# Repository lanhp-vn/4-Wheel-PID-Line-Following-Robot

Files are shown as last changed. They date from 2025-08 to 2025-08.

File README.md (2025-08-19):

# 4-Wheel Line Following Robot

An Arduino-based autonomous line following robot designed for competitive racing and educational purposes. This project demonstrates advanced robotics concepts including PID control, sensor fusion, obstacle avoidance, and differential drive navigation.

**Video Demo:** [Watch the robot in action](https://www.youtube.com/watch?v=uRDj3uBrsaU)

## Project Overview

This project represents my complete understanding and implementation of advanced robotics concepts. Every library, algorithm, and control logic was personally developed, written, and tested by me through extensive experimentation and iterative development.

## Key Features

- **4-Wheel Differential Drive**: Precise control with independent motor control
- **Advanced Line Following**: BFD-1000 5-channel IR sensor array with custom PID control algorithm
- **Obstacle Avoidance**: Personal ultrasonic sensor integration and avoidance logic
- **Encoder Feedback**: Custom H206 encoder reading and calculation algorithms
- **Kalman Filtering**: Personal sensor noise reduction implementation
- **Modular Design**: Easy component mounting and maintenance
- **Competition Ready**: Optimized for line following competitions through personal testing and tuning

## Hardware Components

| Component | Model | Purpose |
|---|---|---|
| **Microcontroller** | Arduino UNO | Main control unit |
| **Line Sensor** | BFD-1000 | 5-channel IR tracking module |
| **Motors** | 4x DC Motors | Differential drive system |
| **Motor Driver** | L298N H-bridge | Motor control and direction |
| **Distance Sensors** | HC-SR04 Ultrasonic | Obstacle detection |
| **Encoders** | H206 | Position and speed feedback |
| **Chassis** | Acrylic | Lightweight and modular design |
| **Power** | External Battery Pack | Barrel jack connection |

## Project Structure

```
main/
├── main.ino                    # Main robot program (100% custom written by me)
├── libraries/                   # Custom Arduino libraries
│   ├── BFD1000/               # Line sensor library
│   ├── PID Calculation/       # PID control algorithms
│   ├── Test encoder lib/      # Encoder testing
│   ├── Test LF sensor/        # Line sensor testing
│   ├── Test motor/            # Motor driver testing
│   ├── Test obstacle avoidance/ # Obstacle avoidance testing
│   └── Ultrasonic - Measuring distance/ # Distance measurement
├── 3d_models/                 # 3D printable parts
│   ├── adjusting pad v1.stl   # Sensor adjustment mount
│   └── BFD1000 pad v1.stl     # Line sensor mount
└── docs/                      # Documentation and schematics
```

## Personal Development Work

**All libraries and algorithms in this project were personally developed, written, and tested by me.** This includes:

### Libraries
- **Motor_Driver.h/cpp**: L298N motor driver control library
- **LFsensor.h/cpp**: BFD-1000 line sensor interface library
- **Encoder_Read.h/cpp**: H206 encoder reading and calculations library
- **Ultrasonic.h/cpp**:  HC-SR04 ultrasonic sensor control library
- **SimpleKalmanFilter.h/cpp**: sensor noise filtering implementation

### Control Algorithms (Personally Developed)
- **PID Control**: Custom PID algorithm written, tested, and fine-tuned through experimentation
- **Obstacle Avoidance**: Personal obstacle detection and avoidance logic
- **Encoder-Based Navigation**: Custom distance and angle calculation algorithms
- **State Management**: Complete state machine for robot operating modes

### Development Process
Every algorithm, library function, and control logic was:
1. Designed from scratch based on component datasheets
2. Written entirely by me in C++ for Arduino
3. Tested through extensive experimentation with real hardware
4. Fine-tuned through iterative development and performance optimization
5. Integrated into a complete system through systematic testing

## Main Program Development

### main.ino - My Complete Robot Control System
This main Arduino program represents my complete understanding and implementation of:

- **Complete State Machine**: All robot operating modes (line following, obstacle avoidance, turning, etc.)
- **PID Control Integration**: My custom PID algorithm integrated with motor control
- **Sensor Management**: Coordination of all sensors (line sensors, ultrasonic, encoders)
- **Motor Control Logic**: Integration with my custom motor driver library
- **Interrupt Handling**: Custom encoder interrupt routines for precise position tracking
- **Error Handling**: Robust error detection and recovery mechanisms
## Technical Specifications

### PID Parameters
```cpp
const float Kp = 40;    // Proportional gain
const float Ki = 0;      // Integral gain  
const float Kd = 45;     // Derivative gain
const int init_speed = 200;  // Base speed
const int max_speed = 240;   // Maximum speed
```

### Pin Connections
```cpp
// Motor Driver (L298N)
#define ENA A0, ENB A1
#define IN1 4, IN2 5, IN3 6, IN4 7

// Line Sensors (BFD-1000)
#define S1 9, S2 10, S3 11, S4 12, S5 13

// Ultrasonic Sensors
#define Trig 8, Front A2, Right A4, Left A5

// Encoders
#define leftEncoder 2, rightEncoder 3
```

## Getting Started

### Prerequisites
- Arduino IDE 1.8.x or later
- Arduino UNO board
- Required hardware components (see Hardware Components table)

### Installation
1. Clone this repository
2. Open `main/main.ino` in Arduino IDE
3. Connect hardware according to pin definitions
4. Upload to Arduino UNO

## Personal Achievement

This project represents my complete understanding and implementation of advanced robotics concepts:

- **From Theory to Practice**: Implemented PID control, sensor fusion, and navigation algorithms
- **Hardware Integration**: Successfully integrated multiple sensors and actuators
- **Software Architecture**: Designed modular, maintainable code structure
- **Testing & Optimization**: Fine-tuned performance through extensive experimentation
- **Problem Solving**: Developed solutions for real-world robotics challenges

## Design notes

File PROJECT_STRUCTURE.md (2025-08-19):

# Project Structure Overview

## 📁 Complete File Organization

```
4-Wheel-Line-Following-Robot/
├── README.md                    # Main project documentation
├── QUICKSTART.md               # Quick start guide
├── project_config.md           # Technical configuration details
├── PROJECT_STRUCTURE.md        # This file - project overview
├── Class Diagram.docx          # Original class diagram
├── Midterm Assessment.pdf      # Course assessment document
├── robot.heic                  # Robot image
│
├── main/                       # Main source code
│   ├── main.ino                    # Main Arduino program
│   ├── Encoder_Read.cpp            # Encoder library implementation
│   ├── Encoder_Read.h              # Encoder library header
│   ├── LFsensor.cpp                # Line sensor library implementation
│   ├── LFsensor.h                  # Line sensor library header
│   ├── Motor_Driver.cpp            # Motor driver library implementation
│   ├── Motor_Driver.h              # Motor driver library header
│   ├── SimpleKalmanFilter.cpp      # Kalman filter implementation
│   ├── SimpleKalmanFilter.h        # Kalman filter header
│   ├── Ultrasonic.cpp              # Ultrasonic sensor library
│   └── Ultrasonic.h                # Ultrasonic sensor header
│
├── src/libraries/              # Testing and development libraries
│   ├── BFD1000/               # Line sensor testing
│   │   └── BFD1000.ino
│   ├── PID Calculation/       # PID control algorithms
│   │   ├── PID Calculation.ino
│   │   ├── PIDcal.cpp
│   │   └── PIDcal.h
│   ├── Test encoder lib/      # Encoder testing
│   │   ├── Encoder_Read.cpp
│   │   ├── Encoder_Read.h
│   │   └── Test encoder lib.ino
│   ├── Test LF sensor/        # Line sensor testing
│   │   └── sketch_nov13c/
│   │       ├── LFsensor.cpp
│   │       ├── LFsensor.h
│   │       └── sketch_nov13c.ino
│   ├── test motor/            # Motor driver testing
│   │   └── test motor.ino
│   ├── Test obstacle avoidance/ # Obstacle avoidance testing
│   │   ├── Encoder_Read.cpp
│   │   ├── Encoder_Read.h
│   │   ├── Motor_Driver.cpp
│   │   ├── Motor_Driver.h
│   │   ├── SimpleKalmanFilter.cpp
│   │   ├── SimpleKalmanFilter.h
│   │   ├── Test obstacle avoidance.ino
│   │   ├── Ultrasonic.cpp
│   │   └── Ultrasonic.h
│   ├── Test ultrasonic lib/   # Ultrasonic testing
│   │   ├── Test ultrasonic lib.ino
│   │   ├── Ultrasonic.cpp
│   │   └── Ultrasonic.h
│   ├── Turning angles/        # Turning angle testing
│   │   └── Turning angles.ino
│   └── Ultrasonic - Measuring distance/ # Distance measurement
│       └── Measuring distance/
│           ├── Measuring distance.ino
│           ├── UTSN_MeasDist.cpp
│           └── UTSN_MeasDist.h
│
├── src/3d_models/             # 3D printable parts
│   ├── adjusting pad v1.stl   # Sensor adjustment mount
│   ├── adjusting pad v1_0.15mm_PLA_MK3S_24m.gcode
│   ├── BFD1000 pad v1.stl     # Line sensor mount
│   └── BFD1000 pad v1_0.15mm_PLA_MK3S_1h4m.gcode
│
└── docs/                      # Additional documentation
    └── (future documentation files)
```

## 🔄 File Renaming Summary

### Original → New Names
- `Main_program.ino` → `main.ino`
- `Main_program/` → `main/` (main source code)
- `Arduino Libs - Robot Studio/` → `main/libraries/`
- `3Dparts_LineFollowingSensor/` → `main/3d_models/`

### Key Benefits of New Structure
1. **Clear Separation**: Source code, libraries, and 3D models are clearly organized
2. **Standard Naming**: Follows common Arduino project conventions
3. **Easy Navigation**: Logical grouping of related files
4. **Professional Appearance**: Suitable for GitHub and portfolio use

## 📚 Library Organization

### Core Libraries (in src/)
These are the main libraries used by the robot:
- **Motor_Driver**: Controls L298N motor driver
- **LFsensor**: Interfaces with BFD-1000 line sensor
- **Encoder_Read**: Handles H206 encoder readings
- **Ultrasonic**: Manages HC-SR04 sensors
- **SimpleKalmanFilter**: Reduces sensor noise

### Testing Libraries (in src/libraries/)
These are for development and testing:
- **BFD1000**: Line sensor testing and calibration
- **PID Calculation**: PID algorithm development
- **Test encoder lib**: Encoder functionality testing
- **Test LF sensor**: Line sensor testing
- **test motor**: Motor driver testing
- **Test obstacle avoidance**: Obstacle avoidance testing
- **Test ultrasonic lib**: Ultrasonic sensor testing
- **Turning angles**: Turning precision testing

## 🎯 Usage Guidelines

### For End Users
1. Use files in `main/` for the main robot
2. Refer to `README.md` for setup instructions
3. Use `QUICKSTART.md` for quick setup
4. Check `project_config.md` for technical details

### For Developers
1. Use `main/libraries/` for component testing
2. Modify main code in `main/main.ino`
3. Test individual components before integration
4. Use provided test libraries for debugging

### For Educators
1. Use as a complete robotics project example
2. Demonstrate PID control implementation
3. Show sensor fusion techniques
4. Illustrate modular software design

## 🚀 GitHub Repository Structure

This structure is optimized for GitHub with:
- Clear documentation at the top level
- Organized source code in `main/`
- Comprehensive testing libraries
- 3D models for hardware reproduction
- Professional README and guides

## 📝 Maintenance Notes

- Keep original files as backup until new structure is verified
- Update documentation when modifying code
- Test all components after any changes
- Maintain consistent naming conventions
- Version control all changes

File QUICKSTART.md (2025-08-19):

# Quick Start Guide

Get your 4-Wheel Line Following Robot up and running in minutes!

## 🚀 Quick Setup

### 1. Hardware Assembly
- Mount Arduino UNO on the acrylic chassis
- Connect BFD-1000 line sensor to pins 9-13
- Connect L298N motor driver to pins 4-7, A0-A1
- Connect ultrasonic sensors to pins 8, A2, A4, A5
- Connect encoders to pins 2-3
- Connect external battery pack via barrel jack

### 2. Software Setup
1. **Download Code**: Clone this repository
2. **Open Arduino IDE**: Open `main/main.ino`
3. **Select Board**: Tools → Board → Arduino Uno
4. **Select Port**: Tools → Port → (your Arduino port)
5. **Upload**: Click Upload button or Ctrl+U

### 3. First Test
1. **Power On**: Connect battery pack
2. **Place on Line**: Put robot on a black line on white surface
3. **Watch it Go**: Robot should automatically follow the line!

## ⚡ Quick Configuration

### Basic PID Tuning
```cpp
// In line_following_robot.ino, adjust these values:
const float Kp = 40;    // Start with 40, increase for faster response
const float Ki = 0;      // Keep at 0 initially
const float Kd = 45;     // Start with 45, increase for stability
```

### Speed Adjustment
```cpp
const int init_speed = 200;  // Base speed (0-255)
const int max_speed = 240;   // Maximum speed
```

### Obstacle Detection
```cpp
const float detect_obstacle = 20;  // Detection distance in cm
```

## 🔧 Common Issues & Solutions

### Robot Not Moving
- Check motor connections
- Verify battery voltage
- Check motor driver connections

### Poor Line Following
- Clean line sensor lenses
- Adjust PID values
- Check line contrast (black on white)

### Encoder Errors
- Verify encoder connections
- Check interrupt pins (2, 3)
- Ensure proper mounting

### Ultrasonic Issues
- Check sensor connections
- Verify trigger/echo pins
- Clean sensor surfaces

## 📊 Performance Optimization

### For Speed
- Increase `Kp` value
- Increase `init_speed`
- Reduce `Kd` value

### For Stability
- Increase `Kd` value
- Reduce `init_speed`
- Fine-tune `Kp`

### For Obstacle Avoidance
- Adjust `detect_obstacle` distance
- Modify avoidance algorithm in code
- Test different sensor positions

## 🎯 Competition Tips

1. **Calibrate Sensors**: Test on actual competition surface
2. **Optimize PID**: Fine-tune for track characteristics
3. **Battery Check**: Ensure full charge before competition
4. **Speed vs Accuracy**: Find optimal balance for your track
5. **Practice Runs**: Test on similar track layouts

## 📱 Serial Monitor

Connect to Arduino via Serial Monitor (9600 baud) to see:
- Current operating mode
- Sensor readings
- PID calculations
- Error values

## 🆘 Need Help?

- Check the main [README.md](README.md) for detailed information
- Review [project_config.md](project_config.md) for technical details
- Test individual components using the test libraries in `src/libraries/`
- Ensure all connections match the pin definitions

---

**Happy Robot Building! 🤖**

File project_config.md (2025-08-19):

# Project Configuration

## Pin Definitions

### Motor Driver (L298N)
```cpp
#define ENA A0    // Left motor speed control
#define ENB A1    // Right motor speed control
#define IN1 4     // Left motor direction 1
#define IN2 5     // Left motor direction 2
#define IN3 6     // Right motor direction 1
#define IN4 7     // Right motor direction 2
```

### Line Sensors (BFD-1000)
```cpp
#define S1 9      // Leftmost sensor
#define S2 10     // Left sensor
#define S3 11     // Center sensor
#define S4 12     // Right sensor
#define S5 13     // Rightmost sensor
```

### Ultrasonic Sensors
```cpp
#define Trig 8    // Trigger pin (shared)
#define Front A2  // Front sensor echo
#define Right A4  // Right sensor echo
#define Left A5   // Left sensor echo
```

### Encoders
```cpp
#define leftEncoder 2   // Left wheel encoder
#define rightEncoder 3  // Right wheel encoder
```

## Control Parameters

### PID Control
```cpp
const float Kp = 40;           // Proportional gain
const float Ki = 0;            // Integral gain
const float Kd = 45;           // Derivative gain
const int init_speed = 200;    // Base speed
const int min_speed = 0;       // Minimum speed
const int max_speed = 240;     // Maximum speed
const int turn_speed = 170;    // Turning speed
```

### Obstacle Detection
```cpp
const float detect_obstacle = 20;  // Detection distance in cm
const float front_obstacle = 20;   // Front obstacle threshold
```

### Encoder Configuration
```cpp
const int delay_90deg = 450;   // Delay for 90-degree turn
```

### Kalman Filter
```cpp
const float mea_e = 2;         // Measurement uncertainty
const float est_e = 2;         // Estimation uncertainty
const float q = 0.07;          // Process variance
```

## Operating Modes

```cpp
const int FINISH = 0;              // Finish line detected
const int FOLLOWING_LINE = 1;      // Normal line following
const int STOP = 2;                // No line detected
const int TURNING_left = 3;        // Turning left
const int TURNING_right = 4;       // Turning right
const int AVOIDING_OBSTACLE = 5;   // Obstacle avoidance
```

## Hardware Specifications

### Motors
- **Type**: DC Motors with H-bridge control
- **Control**: PWM speed control (0-255)
- **Direction**: Bidirectional control

### Sensors
- **Line Sensor**: BFD-1000 5-channel IR array
- **Distance**: HC-SR04 ultrasonic (2-400cm range)
- **Encoders**: H206 quadrature encoders

### Power
- **Voltage**: External battery pack
- **Connection**: Barrel jack
- **Regulation**: Arduino UNO voltage regulation

## Calibration Values

### Line Sensor Thresholds
- **Black Line**: Digital LOW (0)
- **White Surface**: Digital HIGH (1)

### Encoder Calculations
- **Wheel Diameter**: Configured in Encoder_Read library
- **Pulses per Revolution**: 40 pulses per revolution
- **Distance Calculation**: Based on wheel circumference

### Ultrasonic Calibration
- **Speed of Sound**: 340 m/s (standard)
- **Temperature Compensation**: Not implemented
- **Filtering**: Kalman filter for noise reduction

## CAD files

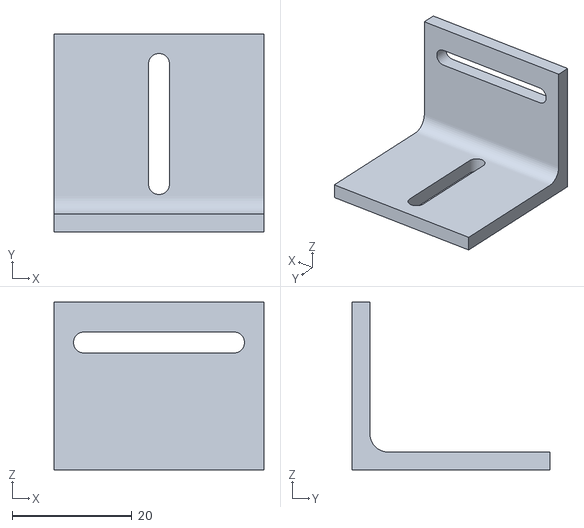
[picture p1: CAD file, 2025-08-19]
main/3d_models/BFD1000 pad v1.stl
35.0 x 33.0 x 28.0

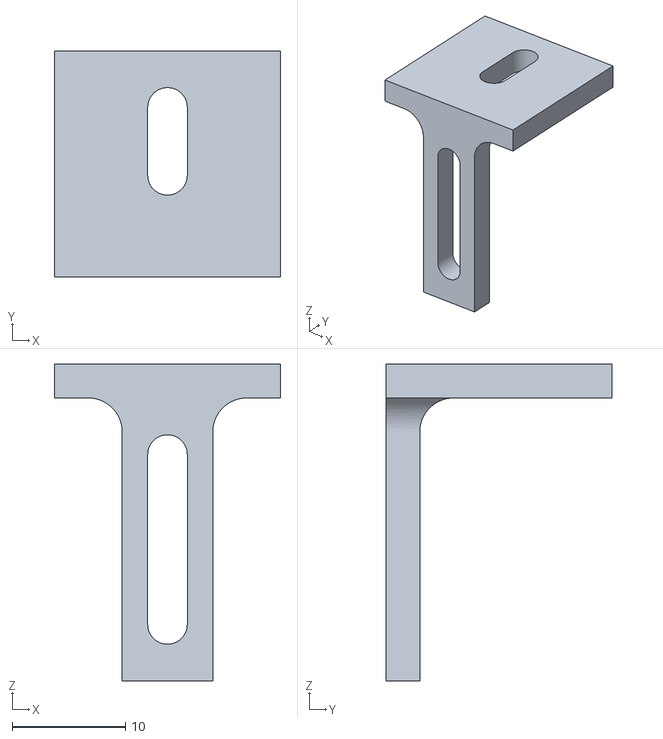
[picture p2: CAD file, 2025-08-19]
main/3d_models/adjusting pad v1.stl
20.0 x 20.0 x 28.0

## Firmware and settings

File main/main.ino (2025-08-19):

//**********Include libraries**********//
#include "Motor_Driver.h"
#include "Encoder_Read.h"
#include "Ultrasonic.h"
#include "LFsensor.h"
#include "SimpleKalmanFilter.h"


//**********4 Channels Ultrasonic Sensors**********//
#define Trig 8
#define Front A2
#define Right A4
#define Left A5

//**********6 Channels L298N Motor Driver**********//
#define ENA A0
#define ENB A1
#define IN1 4
#define IN2 5
#define IN3 6
#define IN4 7
//**********5 Channels BFD1000 LF Sensor**********//
#define S1 9
#define S2 10
#define S3 11
#define S4 12
#define S5 13
//**********2 Channels H206 Encoders**********//
#define leftEncoder 2
#define rightEncoder 3


//------Declare SWITCH-CASE MODES------//
const int FINISH = 0;
const int FOLLOWING_LINE = 1;
const int STOP = 2;
const int TURNING_left = 3;
const int TURNING_right = 4;
const int AVOIDING_OBSTACLE = 5;
int obstacle;
float front_obstacle = 20; //in centimeters

//------Declare variables for Encoder_Read------//
volatile int left_count, right_count, rotation, rpm;
unsigned long timetaken, pevtime, dtime, finishtime; //to store millis()
float v, angle, dist, left_count_temp, right_count_temp;

//------Declare variables for rotating direction------//
const int right = 0;
const int left = 1;

//------Declare variables for calculatePID------//
float P, I, D, PIDval;
const float Kp = 40;
const float Ki = 0;
const float Kd = 45;
const int init_speed = 200;
const int min_speed = 0;
const int max_speed = 240;
const int turn_speed = 170;
const int delay_90deg = 450;

//------Declare variables for Ultrasonic------//
float meas_front, meas_left, meas_right;
const float detect_obstacle = 20; //in cm

//------Declare variables for LFsensor------//
int mode;
float error, prev_error;

//------Declare variables for LFsensor------//
const float mea_e = 2; //Measurement uncertainty
const float est_e = 2; //Estimation uncertainty
const float q = 0.07; //Process variance


//------DECLARE CLASSES FOR INCLUDED LIBRARIES------//
SimpleKalmanFilter kf = SimpleKalmanFilter(mea_e, est_e, q);
Motor_Driver driver = Motor_Driver(ENA, ENB, IN1, IN2, IN3, IN4);
Encoder_Read encoder = Encoder_Read();
Ultrasonic UTSN = Ultrasonic(Trig);
LFsensor LFS = LFsensor(S1, S2, S3, S4, S5);



//---------------------------VOID SETUP---------------------------//
void setup() {
  // put your setup code here, to run once:
  Serial.begin(9600);

  //------PINMODE------//
  pinMode(IN1, OUTPUT);
  pinMode(IN2, OUTPUT);
  pinMode(IN3, OUTPUT);
  pinMode(IN4, OUTPUT);

  pinMode(ENA, OUTPUT);
  pinMode(ENB, OUTPUT);

  pinMode(S1, INPUT);
  pinMode(S2, INPUT);
  pinMode(S3, INPUT);
  pinMode(S4, INPUT);
  pinMode(S5, INPUT);

  pinMode(Trig, OUTPUT);
  pinMode(Front, INPUT);
  pinMode(Right, INPUT);
  pinMode(Left, INPUT);

  pinMode(leftEncoder, INPUT);
  pinMode(rightEncoder, INPUT);
  digitalWrite(leftEncoder, HIGH);
  digitalWrite(rightEncoder, HIGH);

  //------VARIABLES------//
  P = I = D = PIDval = 0;
  left_count = right_count = pevtime = dtime = 0;
  left_count_temp = right_count_temp = 0;

  obstacle = 0;

  //------ATTACH INTERRUPTIONS------//
  attachInterrupt(digitalPinToInterrupt(leftEncoder), left_ISR, CHANGE);
  attachInterrupt(digitalPinToInterrupt(rightEncoder), right_ISR, CHANGE);
}



//---------------------------INTERRUPTION FUNCTIONS---------------------------//
void left_ISR()
{
  left_count++;
}

void right_ISR()
{
  right_count++;
  rotation++;
  dtime = millis();
  if(rotation>=40)
  {
    timetaken = millis() - pevtime  ;
    rpm = (1000/timetaken)*60; //rps = 1000/timetaken
    rpm = kf.updateEstimate(rpm);
    pevtime = millis();
    rotation = 0;
  }
}


//---------------------------FUNCTIONS---------------------------//
void setPIDspeed()
{
  P = error;
  I = I + error;
  D = error - prev_error;

  PIDval = (Kp * P) + (Ki * I) + (Kd * D);
  prev_error = error;

  int left_speed = init_speed - PIDval; 
  int right_speed = init_speed + PIDval;

  // The motor speed should not exceed the max PWM value
  left_speed = constrain(left_speed, min_speed, max_speed);
  right_speed = constrain(right_speed, min_speed, max_speed);

  driver.setSpeed(left_speed, right_speed);
}

//*****Allow robot to rotate at specified angle*****//
void turn(float aim_deg, int direction)
{

  float cur_angle = 0;
  float going_angle = 0;

  Serial.println(left_count);
  Serial.println(right_count);

  if (left_count_temp == 0 && right_count_temp == 0)
  {
    left_count_temp = left_count;
    right_count_temp = right_count;
  }
  
  cur_angle = encoder.angle_cal(left_count_temp, right_count_temp);
  Serial.print("cur angle: ");
  Serial.println(cur_angle);

  //Rotate right --> direction = 0
  //Rotate left --> direction = 1
  if (direction == 0)
  {driver.shiftRight();}
  if (direction == 1)
  {driver.shiftLeft();}

  going_angle = encoder.angle_cal(left_count, right_count) - cur_angle;
  Serial.print("going angle: ");
  Serial.println(going_angle);

  if (going_angle >= aim_deg)
  {
    driver.stopCar();
    delay(1000);
    left_count_temp = 0;
    right_count_temp = 0;
  }
}

//*****Allow robot to move at specified distance*****//
void move(float aim_dist) //aim_dist in meters
{
  float cur_dist = 0;
  float going_dist = 0;  

  if (right_count_temp == 0)
  {right_count_temp = right_count;}

  cur_dist = encoder.dist_cal(right_count_temp);
  Serial.print("current dist: "); 
  Serial.println(cur_dist);

  driver.forward();

  going_dist = encoder.dist_cal(right_count) - cur_dist;
  Serial.print("going distance: "); 
  Serial.println(going_dist);

  if (going_dist >= aim_dist)
  {
    driver.stopCar();
    delay(1000);
    right_count_temp = 0;
  }
}


//*****Reach finish line by brute-force testing*****//
void BForce_finish(int direction)
{
  int speed = 150;

  driver.setSpeed(speed, speed);

  driver.stopCar();
  delay(1000);

  //Right road --> direction = 0
  //Left road --> direction = 1
  switch(direction)
  {
    case right:
      driver.forward();
      delay(1800);
      driver.stopCar();
      delay(500);
      driver.turn_90deg(right, delay_90deg);
      driver.forward();
      delay(2770);
      driver.stopCar();
      delay(10000);
      break;

    case left:
      driver.forward();
      delay(1500);
      driver.stopCar();
      delay(500);
      driver.turn_90deg(left, delay_90deg);
      driver.forward();
      delay(2770);
      driver.stopCar();
      delay(10000);
      break;
  }
}

//*****Procedure for robot to avoid the obstacle ahead*****//
void obstacle_avoid(int meas_pin)
{
  int speed = 150;
  int X = 500;
  int Z = 1000;
  int Y = 0;
  bool obstacle_ahead = 30;
  bool no_obstacle;

  driver.setSpeed(speed, speed);

  driver.stopCar();
  delay(1000);

  driver.turn_90deg(right, delay_90deg);

  driver.forward();
  delay(X);
  Y += X;
  driver.stopCar();
  delay(1000);

  driver.turn_90deg(left, delay_90deg);

  no_obstacle = UTSN.no_obstacle(meas_front, obstacle_ahead);
  if (no_obstacle == false)
  {
    driver.turn_90deg(right, delay_90deg);
    driver.forward();
    delay(X);
    Y += X;
    driver.stopCar();
    delay(1000);
  }

  driver.forward();
  delay(Z);
  driver.stopCar();
  delay(1000);

  driver.turn_90deg(left, delay_90deg);

  no_obstacle = UTSN.no_obstacle(meas_front, obstacle_ahead);
  if (no_obstacle == false)
  { 
    driver.turn_90deg(right, delay_90deg);
    driver.forward();
    delay(Z/2);
    driver.stopCar();
    delay(1000);
  }

  driver.forward();
  delay(Y+500);
  driver.stopCar();
  delay(1000);

  driver.turn_90deg(right, delay_90deg);
  driver.stopCar();
  delay(1000);
}

//---------------------------FUNCTIONS for TESTING---------------------------//
//*****To test the correctness of rpm's calculation*****//
void test_rpm()
{
  driver.stopCar();
  delay(5000);

  driver.forward();
  delay(60000);

  int RPM = rpm;
  int rpm_compare = right_count/40;

  Serial.print("rpm: ");
  Serial.println(RPM);
  Serial.print("rpm_compare: ");
  Serial.println(rpm_compare);
  Serial.print("right count: ");
  Serial.println(right_count);
}

//*****To test the correctness of distance measured by ultrasonic sensors*****//
void test_UTSN()
{
  meas_front = kf.updateEstimate(UTSN.measDist(Front));
  Serial.print("front:"); Serial.print(meas_front); Serial.println();
  delay(50);
  
  meas_right = kf.updateEstimate(UTSN.measDist(Right));
  Serial.print("right:"); Serial.print(meas_right); Serial.println();
  delay(50);
  
  meas_left = kf.updateEstimate(UTSN.measDist(Left));
  Serial.print("left:"); Serial.print(meas_left); Serial.println();

  Serial.println();

  delay(200);
}

//---------------------------VOID LOOP---------------------------//
void loop() {
  //put your main code here, to run repeatedly:

  //Kalman filter is applied to stabilize the variance of distance measured by the ultrasonic sensor
  meas_front = UTSN.measDist(Front); 

  if (obstacle == 0) //If there is no obstacle ahead
  {
    LFS.readLFsensor();
    error = LFS.errorVal();
    mode = LFS.modeVal();
    Serial.println(mode);
  }
  else if (obstacle == 1) //If obstacle is detected ahead
  {
    mode = AVOIDING_OBSTACLE;
  }

  switch(mode)
  {
    case FINISH: //Go to the finish line
      // BForce_finish(left);
      driver.stopCar();
      prev_error = error;
      break;

    case FOLLOWING_LINE: //Robot moves forward following the PID algorithm
      setPIDspeed();
      driver.forward();
      if (meas_front <= detect_obstacle)
      {obstacle = 1;}
      break;

    case STOP: //Robot detects no line underneath
      driver.stopCar();
      prev_error = error;
      break;
    
    case TURNING_left: //Forcing the robot to not move out of underneath line
      driver.setSpeed(turn_speed, turn_speed);
      driver.turnLeft();
      delay(100);
      driver.stopCar();
      delay(50);
      prev_error = error;
      break;

    case TURNING_right: //Forcing the robot to not move out of underneath line
      driver.setSpeed(turn_speed, turn_speed);
      driver.turnRight();
      delay(100);
      driver.stopCar();
      delay(50);
      prev_error = error;
      break;
    
    case AVOIDING_OBSTACLE: //Robot detects obstacle ahead
      driver.stopCar();
      // delay(1000);
      // obstacle_avoid(meas_front);
      // obstacle = 0;
      prev_error = error;
      break;
  }
}





  

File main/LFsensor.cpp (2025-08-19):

#include "LFsensor.h"

LFsensor::LFsensor(int S1, int S2, int S3, int S4, int S5){
  //Anything you need when initiating your object goes here
  pinMode(S1, INPUT);
  pinMode(S2, INPUT);
  pinMode(S3, INPUT);
  pinMode(S4, INPUT);
  pinMode(S5, INPUT);
  _s1 = S1;
  _s2 = S2;
  _s3 = S3;
  _s4 = S4;
  _s5 = S5;
  FINISH = 0;
  FOLLOWING_LINE = 1;
  STOP = 2;
  TURNING_left = 3;
  TURNING_right = 4;
  error = 0;
  mode = 0;
}

//-------------------------------------------------------------//
/* read line sensors values
LINE_FOLLOWING 	Error Value
1 1 1 0 0  e=3
0 1 0 0 0  e=3
0 1 1 0 0  e=2
1 1 1 1 0  e=1
0 1 1 1 0  e=0
0 0 1 0 0  e=0
0 1 1 1 1  e=-1
0 0 1 1 0  e=-2
0 0 0 1 0  e=-3
0 0 1 1 1  e=-3          

TURNING_left
1 0 0 0 0
1 1 0 0 0

TURNING_right
0 0 0 0 1
0 0 0 1 1

1 1 1 1 1        0 Robot found continuous line: FINISH
0 0 0 0 0        0 Robot found no line: STOP
*/
void LFsensor::readLFsensor()
{
  LFS1 = digitalRead(_s1);
  LFS2 = digitalRead(_s2);
  LFS3 = digitalRead(_s3);
  LFS4 = digitalRead(_s4);
  LFS5 = digitalRead(_s5);

  //MODE = TURNING
  if((LFS1 == 1) && (LFS2 == 0) && (LFS3 == 0) && (LFS4 == 0) && (LFS5 == 0))  
  {mode = TURNING_left;} 
  else if((LFS1 == 1) && (LFS2 == 1) && (LFS3 == 0) && (LFS4 == 0) && (LFS5 == 0))  
  {mode = TURNING_left;}

  else if((LFS1 == 0) && (LFS2 == 0) && (LFS3 == 0) && (LFS4 == 1) && (LFS5 == 1)) 
  {mode = TURNING_right;}
  else if((LFS1 == 0) && (LFS2 == 0) && (LFS3 == 0) && (LFS4 == 0) && (LFS5 == 1)) 
  {mode = TURNING_right;}
  
  //MODE = FOLLOWING_LINE

  else if((LFS1 == 1) && (LFS2 == 1) && (LFS3 == 1) && (LFS4 == 0) && (LFS5 == 0)) 
  {mode = FOLLOWING_LINE; error = 3;}

  else if((LFS1 == 0) && (LFS2 == 1) && (LFS3 == 0) && (LFS4 == 0) && (LFS5 == 0)) 
  {mode = FOLLOWING_LINE; error = 3;}

  else if((LFS1 == 0) && (LFS2 == 1) && (LFS3 == 1) && (LFS4 == 0) && (LFS5 == 0)) 
  {mode = FOLLOWING_LINE; error = 2;}

  else if((LFS1 == 1) && (LFS2 == 1) && (LFS3 == 1) && (LFS4 == 1) && (LFS5 == 0)) 
  {mode = FOLLOWING_LINE; error = 1;}

  else if((LFS1 == 0) && (LFS2 == 1) && (LFS3 == 1) && (LFS4 == 1) && (LFS5 == 0)) 
  {mode = FOLLOWING_LINE; error = 0;}

  else if((LFS1 == 0) && (LFS2 == 0) && (LFS3 == 1) && (LFS4 == 0) && (LFS5 == 0)) 
  {mode = FOLLOWING_LINE; error = 0;}

  else if((LFS1 == 0) && (LFS2 == 1) && (LFS3 == 1) && (LFS4 == 1) && (LFS5 == 1)) 
  {mode = FOLLOWING_LINE; error = -1;}

  else if((LFS1 == 0) && (LFS2 == 0) && (LFS3 == 1) && (LFS4 == 1) && (LFS5 == 0)) 
  {mode = FOLLOWING_LINE; error = -2;}

  else if((LFS1 == 0) && (LFS2 == 0) && (LFS3 == 0) && (LFS4 == 1) && (LFS5 == 0)) 
  {mode = FOLLOWING_LINE; error = -3;}

  else if((LFS1 == 0) && (LFS2 == 0) && (LFS3 == 1) && (LFS4 == 1) && (LFS5 == 1)) 
  {mode = FOLLOWING_LINE; error = -3;}

  //MODE = FINISH
  else if((LFS1 == 1) && (LFS2 == 1) && (LFS3 == 1) && (LFS4 == 1) && (LFS5 == 1)) 
  {mode = FINISH; error = 0;}
  
  //MODE = STOP
  else if((LFS1 == 0) && (LFS2 == 0) && (LFS3 == 0) && (LFS4 == 0) && (LFS5 == 0)) 
  {mode = STOP; error = 0;}
}

//To get the error value in the main program
float LFsensor::errorVal(){return error;}

//To get the mode value in the main program
float LFsensor::modeVal(){return mode;}

//To test the correctness of line following sensors in the main program
void LFsensor::testLineFollowSensor()
{ 
  LFS1 = digitalRead(_s1);
  LFS2 = digitalRead(_s2);
  LFS3 = digitalRead(_s3);
  LFS4 = digitalRead(_s4);
  LFS5 = digitalRead(_s5);
  Serial.print ("LFS: S1 S2 S3 S4 S5  R ==> "); 
  Serial.print (LFS1); 
  Serial.print (" ");
  Serial.print (LFS2); 
  Serial.print (" ");
  Serial.print (LFS3); 
  Serial.print (" ");
  Serial.print (LFS4);
  Serial.print (" "); 
  Serial.println (LFS5); 
  Serial.print ("  ==> ");
}

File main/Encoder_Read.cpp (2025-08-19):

#include "Arduino.h"
#include "Encoder_Read.h"

Encoder_Read::Encoder_Read()
{
  //Initialize all variables to be 0
  prev_ms = 0;
  radius = 0.033; //radius of wheel in meter
}


bool Encoder_Read::noIntrFound(unsigned long dfr_time, int wait_time)
{
  if(millis() - dfr_time > wait_time){return true;}
}

//Calculate robot's velocity
float Encoder_Read::velo_cal(int RPM)
{
  //Velocity = 2π × radius × RPS 
  float v = (2*3.14*radius) * (RPM/60);
  return v;
}

//Calculate robot's distance
float Encoder_Read::dist_cal(int count)
{
  float dist = (2*3.14*radius) * (count/40);
  return dist;
}

//Calculate robot's rotating angle
float Encoder_Read::angle_cal(int leftCount, int rightCount)
{
  float angle_left = (leftCount % 360) * (90/80);
  float angle_right = (rightCount % 360) * (90/80);
  float angle = angle_right - angle_left;  
  return angle;
}
